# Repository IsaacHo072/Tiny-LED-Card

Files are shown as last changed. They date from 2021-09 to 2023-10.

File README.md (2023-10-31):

# Tiny LED Card
 A tiny credit card sized LED light
 
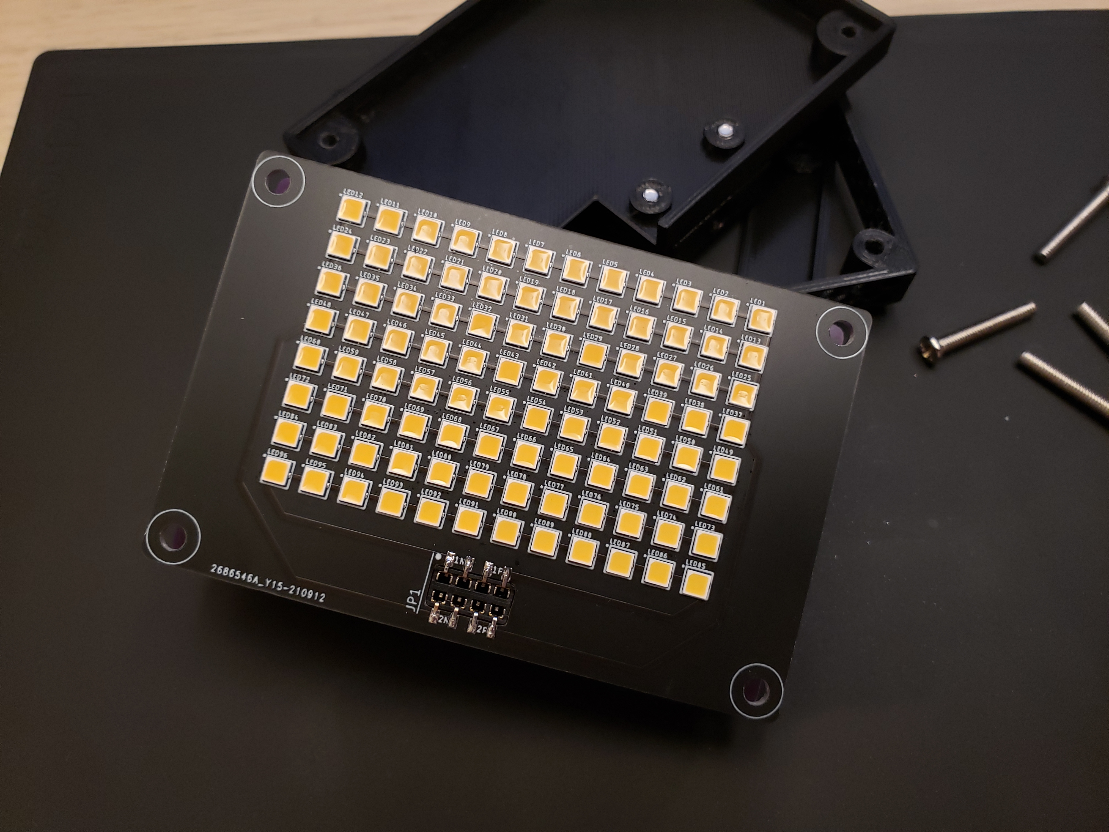
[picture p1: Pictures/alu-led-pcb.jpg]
 

# Hardware
 Currently using 3030 LED and TPS61165 driver.
 
 Update 2022 Feb: It seems that you can't buy the TPS61165 anymore, all places are out of stock. 
 
 Update 2023: TPS61165 back in stock in most marketplace

## 3030 LED
 Luminus Device MP3030-110H
 
 Nominal: 3V 65mA
 
 Maximum: 200mA

## TPS61165
 Boost converter for LEDs in series

 Input voltage: 3-18V
 
 1.2A current limit

## PCB
 Aluminium PCB, single layer, for LED.
 
 FR-4 PCB, Two layers, for driver.
 Components on single side for easy assembly.
 
 2 PCBs connected with 2.54mm headers for upgradability 

## Enclosure
 3D Printed with PLA or any filament
 
 Screws: 4x M3x20
 
 2x M3x12-16mm 
 
# Assembly
 See the BOM for parts.
 Total cost should be under $25

 For the Aluminium PCB, you need a hotplate or a beefy hotair gun.
 It is impossible to solder with a soldering iron 
 
 For the driver PCB, any soldering iron will work, hotplate would also work well.
 
 R1 and R2 are the sense resistor for the LED driver, use the following resistor: 
  for other current see the datasheet of TPS61165
 
 | Resistor (Ω)  | LED Current (each) | Power | 
| ------------- | ------------- | ------------- |
| 1  | 50mA  | 14.4W |
| 0.5  | 100mA  | 28.8W |
| 0.33  | 150mA  | 43.2W |
| 0.25  | 200mA  | 57.6W |

 For the enclosure, print each file once and screw them together.
 
 Glue a heatsink with thermal adhesive at the back of the aluminium PCB after checked working.

## Usage
 Plug a 12V DC power supply in, light will come out from the bright side.
 
 It is not advised to use the Micro USB for power as a large amperage will be needed at 5V. Also, having both accidentally plugged in will damage the Micro USB device.

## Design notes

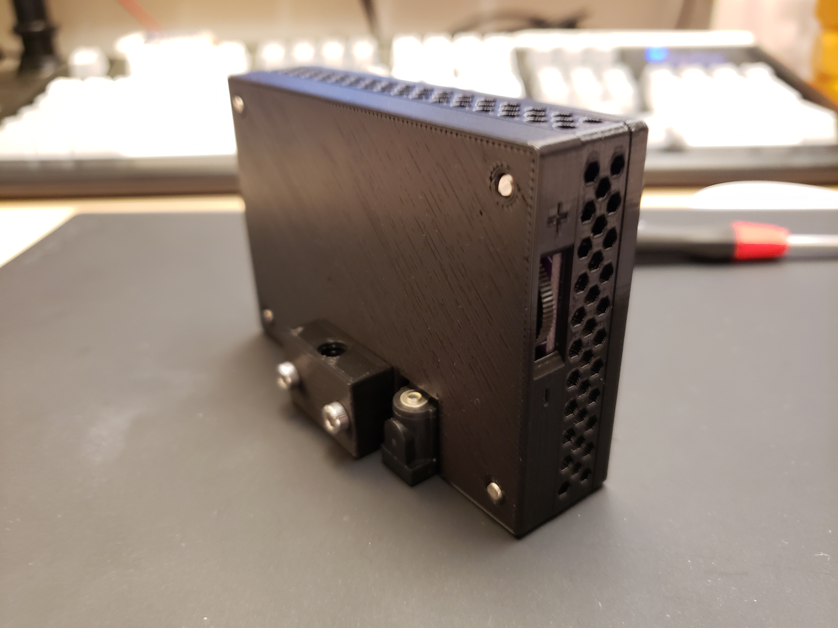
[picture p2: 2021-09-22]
Pictures/back.jpg

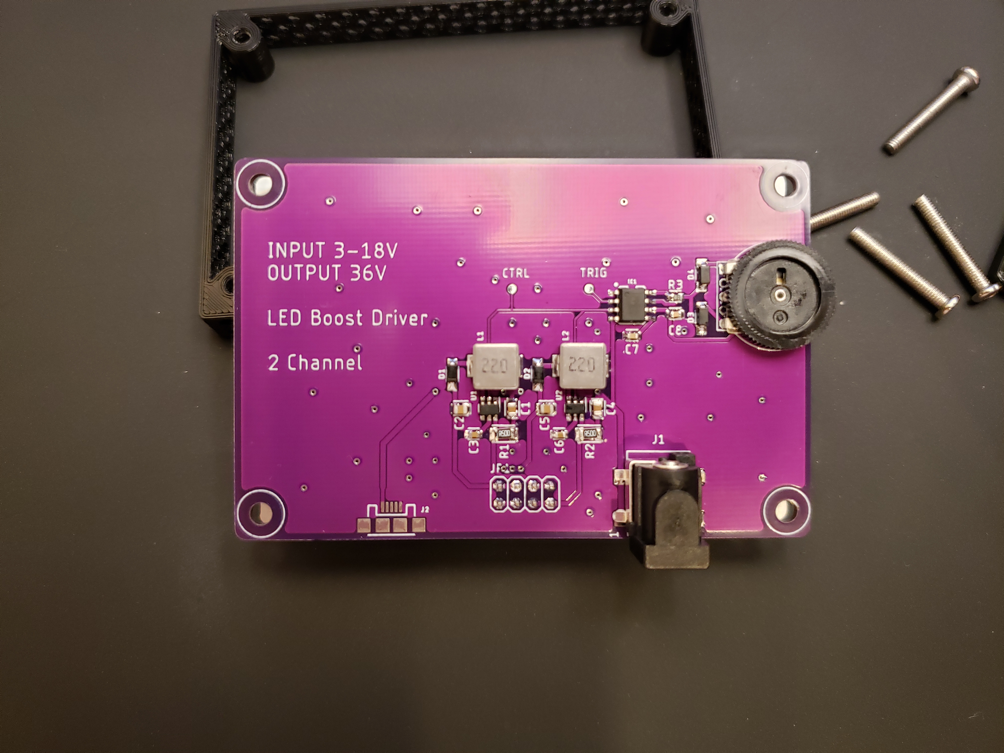
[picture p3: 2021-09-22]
Pictures/driver pcb.jpg

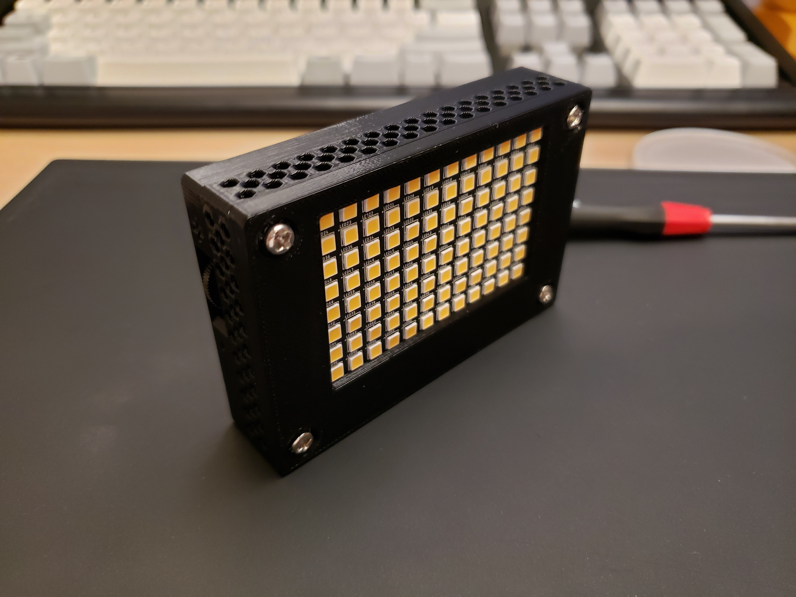
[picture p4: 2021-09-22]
Pictures/front.jpg

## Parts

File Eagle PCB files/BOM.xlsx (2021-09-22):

BOM
Driver
Part | Value | Package | CATEGORY | Remarks
C1 | 4.7uF | 0805 | Capacitor
C2 | 1uF | 0805 | Capacitor
C3 | 220nF | 0603 | Capacitor
C4 | 4.7uF | 0805 | Capacitor
C5 | 1uF | 0805 | Capacitor
C6 | 220nF | 0603 | Capacitor
C7 | 100nF | 0603 | Capacitor
C8 | 1nF | 0603 | Capacitor
D1 | 40V-500MA | SOD-123 | Diode
D2 | 40V-500MA | SOD-123 | Diode
D3 | 40V-500MA | SOD-123 | Diode
D4 | 40V-500MA | SOD-123 | Diode
H1 | MOUNT-HOLE3.2 | MOUNT-HOLE3.2 | Hole
H2 | MOUNT-HOLE3.2 | MOUNT-HOLE3.2 | Hole
H3 | MOUNT-HOLE3.2 | MOUNT-HOLE3.2 | Hole
H4 | MOUNT-HOLE3.2 | MOUNT-HOLE3.2 | Hole
IC1 | NE555 | SO08 | IC
J1 | DC5525 | SMD DC Power Jack | Connector
J2 |  | USB_MICRO-B_SMT |  | Not used
JP1 | PINHD-2X4 | PINHD-2X4 | Connector
L1 | 22uH | SMD-2P-L6.0XW6.0XH3.0MM
L2 | 22uH | SMD-2P-L6.0XW6.0XH3.0MM
R1 | 1R | 1206 | Resistor | Rset
R2 | 1R | 1206 | Resistor | Rset
R3 | 1k | 0603 | Resistor
U1 | TPS61165DBVR | SOT-23 | IC
U2 | TPS61165DBVR | SOT-23 | IC
VR1 | 100k | B104 (100K) 3 Pins | potentiometer
LED Board
LED1-96 | MP3030-110H | MP3030 | LED | Any 3V MP3030 LED could work
JP1 |  | SMD 2x4 | Connector | Sand the corners if it doesn’t fit

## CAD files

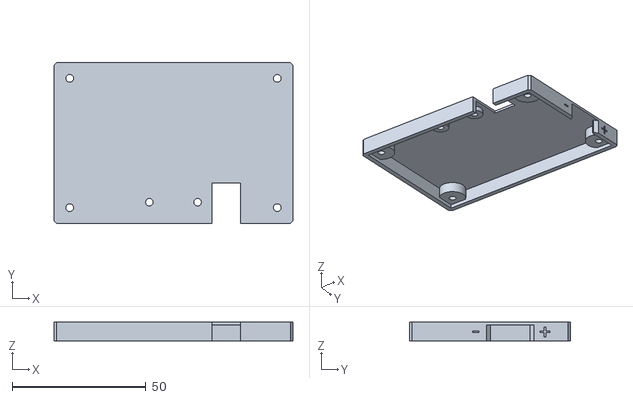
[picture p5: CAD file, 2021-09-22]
Enclosure/backside - driver.stl
89.2 x 60.2 x 7.00

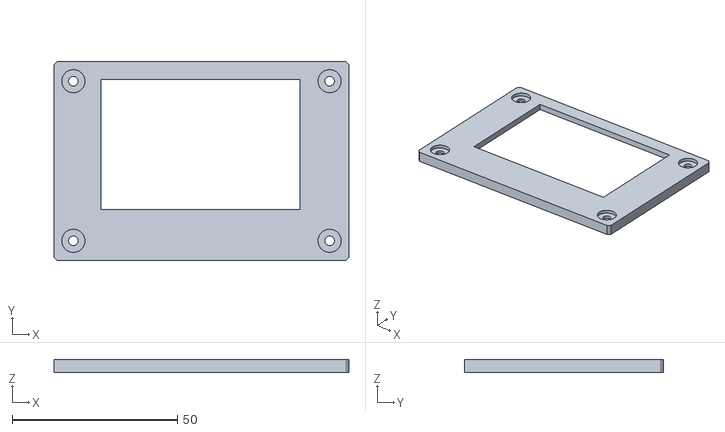
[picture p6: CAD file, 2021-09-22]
Enclosure/front - bezel.stl
89.2 x 60.2 x 3.80

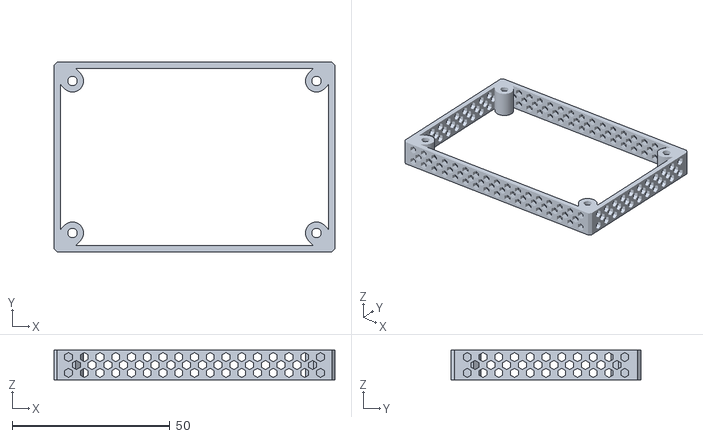
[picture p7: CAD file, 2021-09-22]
Enclosure/middle.stl
89.2 x 60.2 x 9.40

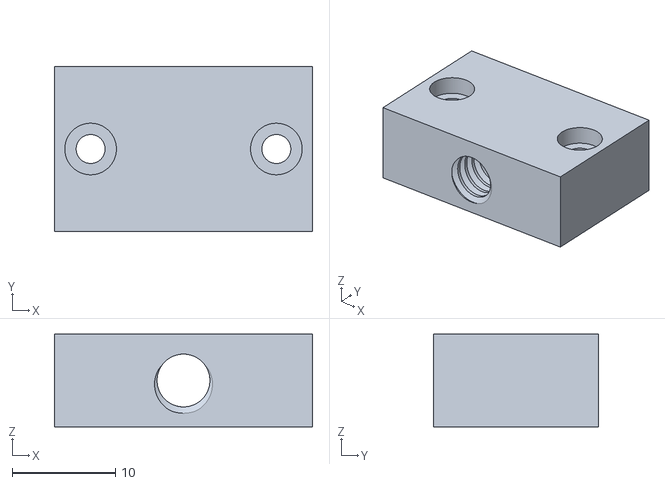
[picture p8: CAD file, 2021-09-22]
Enclosure/1-4in - 20 screw hole mount.stl
25.0 x 16.0 x 9.00

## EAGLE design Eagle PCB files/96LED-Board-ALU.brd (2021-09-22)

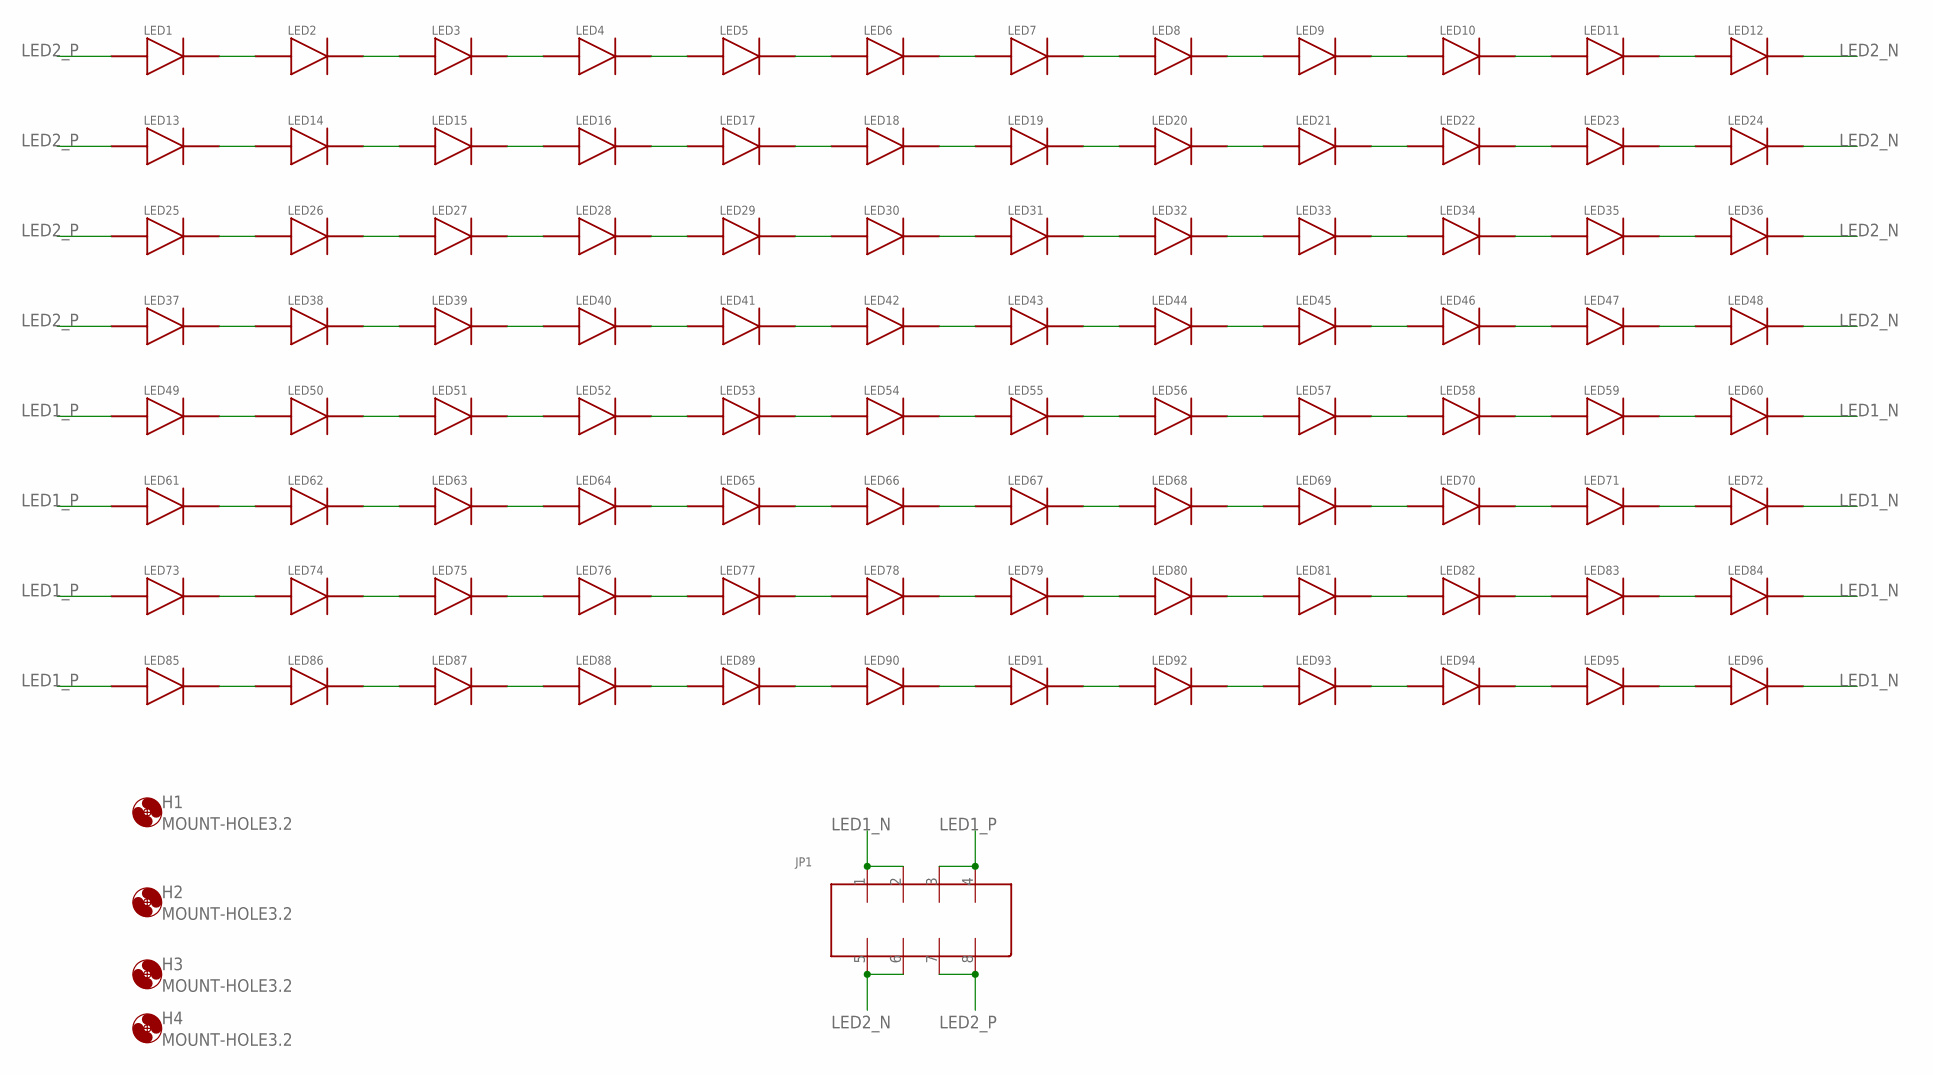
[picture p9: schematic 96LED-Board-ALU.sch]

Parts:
H1, H2, H3, H4: MOUNT-HOLE3.2; 3,2
JP1: 2X8P_2.54_FEMALE; 2X8_PIN_SMD_2.54-FEMALE
LED1, LED2, LED3, LED4, LED5, LED6, LED7, LED8, LED9, LED10, LED11, LED12, LED13, LED14, LED15, LED16, LED17, LED18, LED19, LED20, LED21, LED22, LED23, LED24, LED25, LED26, LED27, LED28, LED29, LED30, LED31, LED32, LED33, LED34, LED35, LED36, LED37, LED38, LED39, LED40, LED41, LED42, LED43, LED44, LED45, LED46, LED47, LED48, LED49, LED50, LED51, LED52, LED53, LED54, LED55, LED56, LED57, LED58, LED59, LED60, LED61, LED62, LED63, LED64, LED65, LED66, LED67, LED68, LED69, LED70, LED71, LED72, LED73, LED74, LED75, LED76, LED77, LED78, LED79, LED80, LED81, LED82, LED83, LED84, LED85, LED86, LED87, LED88, LED89, LED90, LED91, LED92, LED93, LED94, LED95, LED96: MP3030_N

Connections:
LED1_N: JP1.1, JP1.2, LED60.2, LED72.2, LED84.2, LED96.2
LED1_P: JP1.3, JP1.4, LED49.1, LED61.1, LED73.1, LED85.1
LED2_N: JP1.5, JP1.6, LED12.2, LED24.2, LED36.2, LED48.2
LED2_P: JP1.7, JP1.8, LED1.1, LED13.1, LED25.1, LED37.1
unnamed: LED1.2, LED2.1
unnamed: LED2.2, LED3.1
unnamed: LED3.2, LED4.1
unnamed: LED4.2, LED5.1
unnamed: LED5.2, LED6.1
unnamed: LED6.2, LED7.1
unnamed: LED7.2, LED8.1
unnamed: LED8.2, LED9.1
unnamed: LED9.2, LED10.1
unnamed: LED10.2, LED11.1
unnamed: LED11.2, LED12.1
unnamed: LED13.2, LED14.1
unnamed: LED14.2, LED15.1
unnamed: LED15.2, LED16.1
unnamed: LED16.2, LED17.1
unnamed: LED17.2, LED18.1
unnamed: LED18.2, LED19.1
unnamed: LED19.2, LED20.1
unnamed: LED20.2, LED21.1
unnamed: LED21.2, LED22.1
unnamed: LED22.2, LED23.1
unnamed: LED23.2, LED24.1
unnamed: LED25.2, LED26.1
unnamed: LED26.2, LED27.1
unnamed: LED27.2, LED28.1
unnamed: LED28.2, LED29.1
unnamed: LED29.2, LED30.1
unnamed: LED30.2, LED31.1
unnamed: LED31.2, LED32.1
unnamed: LED32.2, LED33.1
unnamed: LED33.2, LED34.1
unnamed: LED34.2, LED35.1
unnamed: LED35.2, LED36.1
unnamed: LED37.2, LED38.1
unnamed: LED38.2, LED39.1
unnamed: LED39.2, LED40.1
unnamed: LED40.2, LED41.1
unnamed: LED41.2, LED42.1
unnamed: LED42.2, LED43.1
unnamed: LED43.2, LED44.1
unnamed: LED44.2, LED45.1
unnamed: LED45.2, LED46.1
unnamed: LED46.2, LED47.1
unnamed: LED47.2, LED48.1
unnamed: LED49.2, LED50.1
unnamed: LED50.2, LED51.1
unnamed: LED51.2, LED52.1
unnamed: LED52.2, LED53.1
unnamed: LED53.2, LED54.1
unnamed: LED54.2, LED55.1
unnamed: LED55.2, LED56.1
unnamed: LED56.2, LED57.1
unnamed: LED57.2, LED58.1
unnamed: LED58.2, LED59.1
unnamed: LED59.2, LED60.1
unnamed: LED61.2, LED62.1
unnamed: LED62.2, LED63.1
unnamed: LED63.2, LED64.1
unnamed: LED64.2, LED65.1
unnamed: LED65.2, LED66.1
unnamed: LED66.2, LED67.1
unnamed: LED67.2, LED68.1
unnamed: LED68.2, LED69.1
unnamed: LED69.2, LED70.1
unnamed: LED70.2, LED71.1
unnamed: LED71.2, LED72.1
unnamed: LED73.2, LED74.1
unnamed: LED74.2, LED75.1
unnamed: LED75.2, LED76.1
unnamed: LED76.2, LED77.1
unnamed: LED77.2, LED78.1
unnamed: LED78.2, LED79.1
unnamed: LED79.2, LED80.1
unnamed: LED80.2, LED81.1
unnamed: LED81.2, LED82.1
unnamed: LED82.2, LED83.1
unnamed: LED83.2, LED84.1
unnamed: LED85.2, LED86.1
unnamed: LED86.2, LED87.1
unnamed: LED87.2, LED88.1
unnamed: LED88.2, LED89.1
unnamed: LED89.2, LED90.1
unnamed: LED90.2, LED91.1
unnamed: LED91.2, LED92.1
unnamed: LED92.2, LED93.1
unnamed: LED93.2, LED94.1
unnamed: LED94.2, LED95.1
unnamed: LED95.2, LED96.1

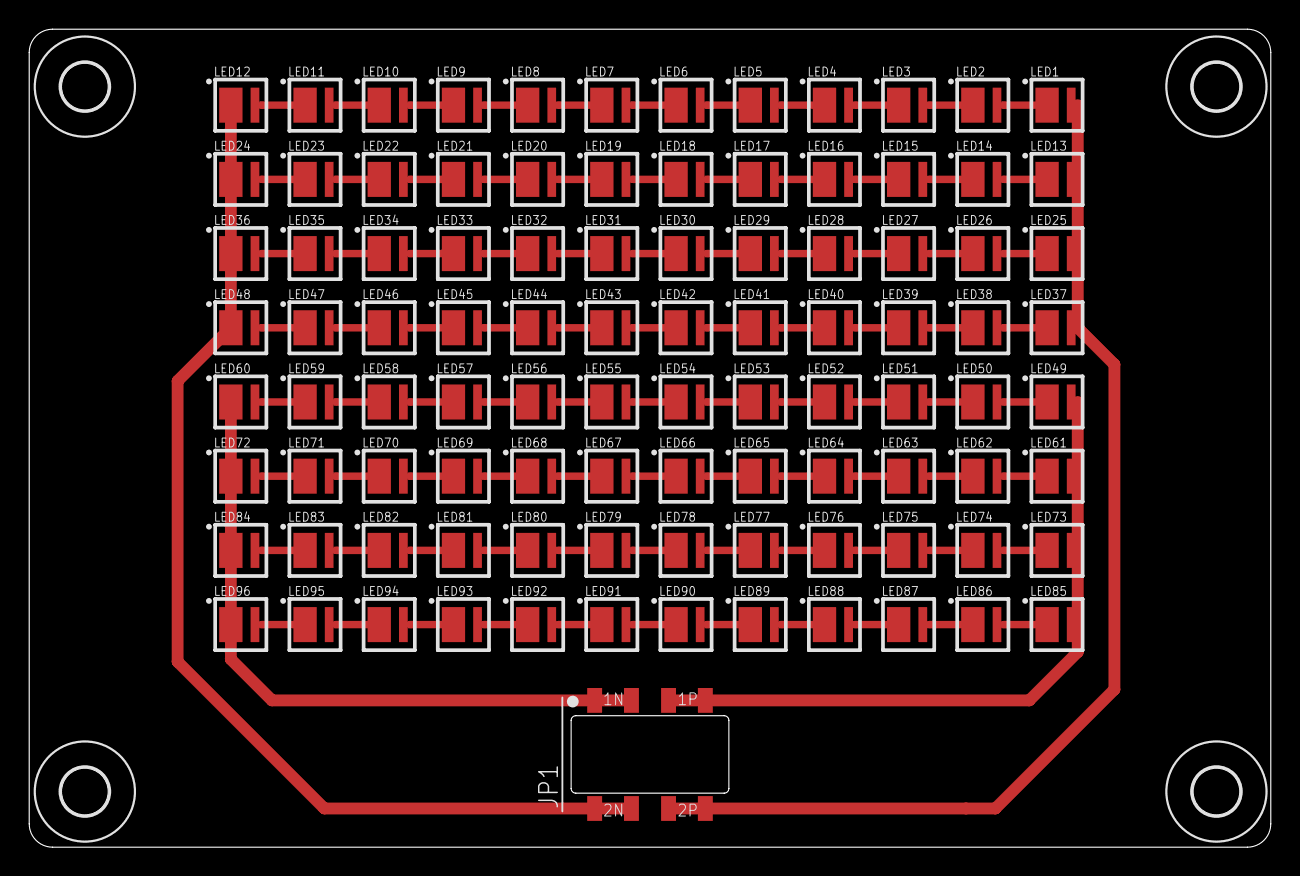
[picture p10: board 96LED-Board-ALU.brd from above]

Board: 2 copper layers, 85.0 x 56.0 mm, 101 parts (0 on the bottom side), 92 nets.

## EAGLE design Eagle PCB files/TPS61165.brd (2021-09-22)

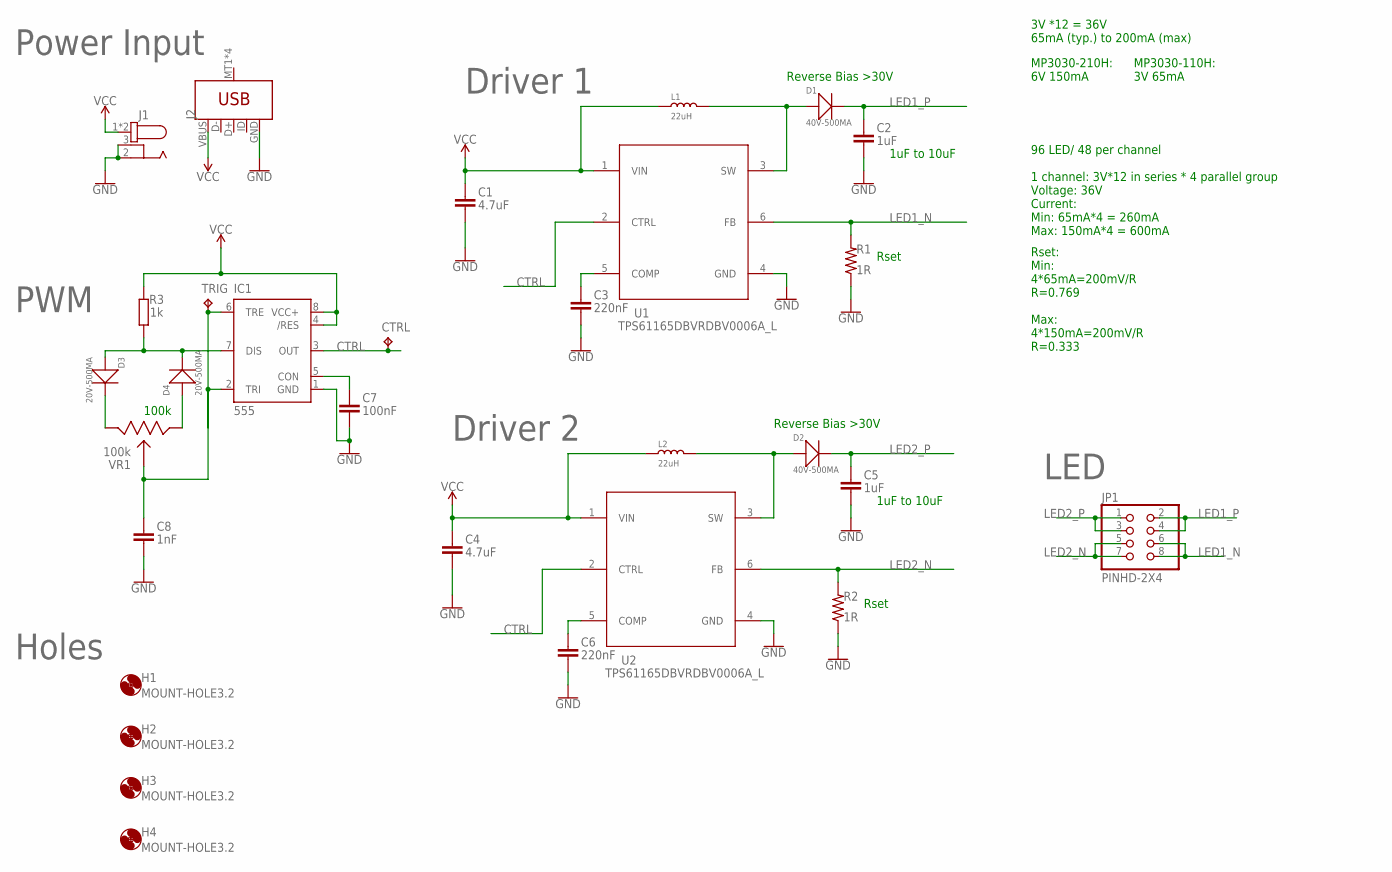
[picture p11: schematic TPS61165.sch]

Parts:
C1, C4: 4.7uF; CAPC2012X110
C2, C5: 1uF; CAPC2012X110
C3, C6: 220nF; CAPC1608X85
C7: 100nF; CAPC1608X85
C8: 1nF; CAPC1608X85
CTRL: TPB1,27; B1,27
D1, D2: 40V-500MA; SOD-123
D3, D4: 20V-500MA; SOD-123
H1, H2, H3, H4: MOUNT-HOLE3.2; 3,2
IC1: 555; SO08
J1: 694108106102
J2: USB_MICRO-B_SMT; USB-MICROB
JP1: PINHD-2X4; 2X04
L1, L2: 22uH; SMD-2P-L6.0XW6.0XH3.0MM
R1, R2: 1R; RESC3216X70
R3: 1k; RESC1608X60
TRIG: TPB1,27; B1,27
U1, U2: TPS61165DBVRDBV0006A_L; DBV0006A_L
VR1: 100k; B104-5PIN

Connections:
COMP: C3.1, U1.5 (COMP)
COMP1: C6.1, U2.5 (COMP)
CON: C7.1, IC1.5 (CON)
CTRL: CTRL.TP, IC1.3 (OUT), U1.2 (CTRL), U2.2 (CTRL)
DISCHARGE: D3.+, D4.-, IC1.7 (DIS), R3.1
GND: C1.2, C2.2, C3.2, C4.2, C5.2, C6.2, C7.2, C8.2, IC1.1 (GND), J1.2, J1.3, J2.GND, R1.1, R2.1, U1.4 (GND), U2.4 (GND)
LED1_N: JP1.6, JP1.8, R1.2, U1.6 (FB)
LED1_P: C2.1, D1.-, JP1.2, JP1.4
LED2_N: JP1.5, JP1.7, R2.2, U2.6 (FB)
LED2_P: C5.1, D2.-, JP1.1, JP1.3
unnamed: D3.-, VR1.P$3
unnamed: D4.+, VR1.P$1
SW: D1.+, L1.2, U1.3 (SW)
SW1: D2.+, L2.2, U2.3 (SW)
TRIGGER: C8.1, IC1.2 (TRI), IC1.6 (TRE), TRIG.TP, VR1.NOT_P$2
VCC: C1.1, C4.1, IC1.4 (/RES), IC1.8 (VCC+), J1.1, J1.A1 (1), J2.VBUS, L1.1, L2.1, R3.2, U1.1 (VIN), U2.1 (VIN)

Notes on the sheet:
MP3030-210H: 6V 150mA
MP3030-110H: 3V 65mA
Rset
1uF to 10uF
Reverse Bias >30V
3V *12 = 36V 65mA (typ.) to 200mA (max)
100k
Power Input
PWM
Driver 1
Driver 2
Holes
Rset: Min: 4*65mA=200mV/R R=0.769 Max: 4*150mA=200mV/R R=0.333
96 LED/ 48 per channel 1 channel: 3V*12 in series * 4 parallel group Voltage: 36V Current: Min: 65mA*4 = 260mA Max: 150mA*4 = 600mA
LED

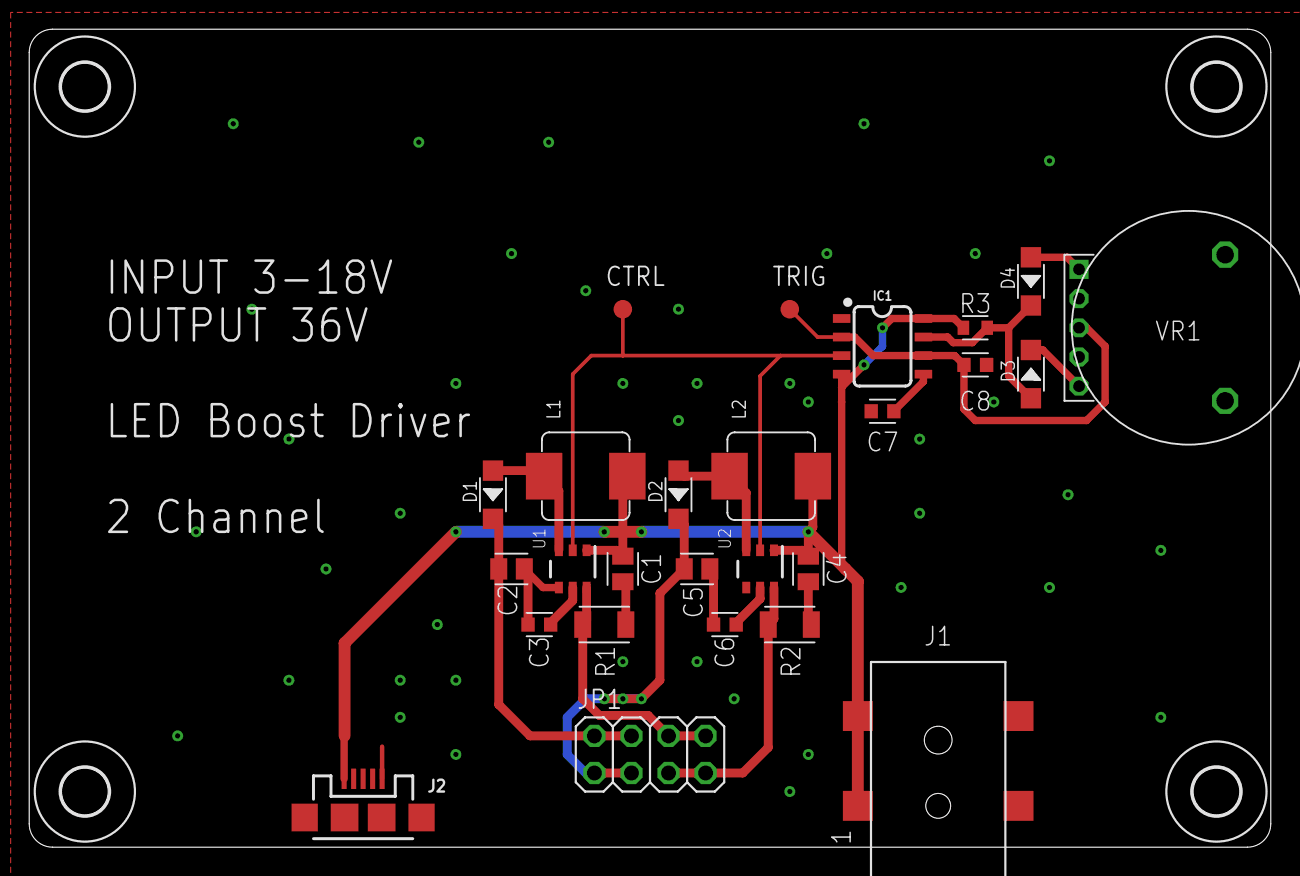
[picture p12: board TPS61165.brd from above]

Board: 2 copper layers, 85.0 x 56.0 mm, 30 parts (0 on the bottom side), 16 nets.

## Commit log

2021-08-30 Update Eagle files
    [mainboard.brd, mainboard.sch]
2021-09-22 Updated PCB files
    [96LED-Board-ALU.brd, 96LED-Board-ALU.sch, TPS61165.brd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]
2021-09-22 Added Enclosure STL
    [1-4in - 20 screw hole mount.stl, backside - driver.stl, front - bezel.stl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]
2021-09-22 Added BOM file
    [BOM.xlsx]

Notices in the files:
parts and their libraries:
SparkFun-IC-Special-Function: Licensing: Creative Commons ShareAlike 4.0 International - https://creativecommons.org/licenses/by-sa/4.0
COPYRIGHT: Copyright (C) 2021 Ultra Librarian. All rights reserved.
